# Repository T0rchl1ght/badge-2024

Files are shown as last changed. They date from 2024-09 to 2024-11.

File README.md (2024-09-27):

# OpenTaxus 

| [Readme](/) | [The Attribution Game](/attribution) | [Trick or Treat Game](/trickortreat) | [Badge Hardware](/hardware) |
| --- | --- | --- | --- |

Opentaxus is a permissively licensed set of hardware, software, and tooling to help as a starting point for customized conference badges.

## Motivation
Electronic conference badges are a well appreciated feature of an event, but very quickly become large, complicated projects. Typically there's custom hardware, custom embedded software, and sometimes much more. Every one of thos parts has the potential for schedule delays or causing the whole project to fail. Meanwhile, there's almost always a very hard deadline.

OpenTaxus is intended to get you started with a working system, allowing you to customize only as much as you want to or have time to. You are encouranged to use any or all of the parts of OpenTaxus for your own project

## Badge Games

There are currently two games for OpenTaxus. Each is in it's own subdirectory. Right now you'll just pick one (or make a new one) for your conference badge:

### [The Attribution Game](/attribution)

Similar to the board game Clue or some versions of Carmen Sandiego,
you need to figure out who the threat actor, attack tool, and victim
are for each round of the game. You do this by trading cards (or
'clues') as well as your self-entered alibi name with others
at the conference.

The Attribution Game was designed for [LABScon 2023](https://www.labscon.io/) and then revised and improved for [BSidesSF 2024](https://bsidessf.org/)

### [Trick or Treat Game](/trickortreat) 

In this game, you Trick-or-Treat, trading virtual candy with other conference attendees. Once you have collected enough, you can cash out your virtual candy for real candy or prizes.

The Trick or Treat Game was designed for [BSidesPDX 2024](https://bsidespdx.org/)

## Repo Contents

This repository contains the hardware and software for the badge and multiple games. We hope it is useful for those who wish to hack the badges and game, anyone who wants to use the badge to learn some circuitpython, as well as others who might like to reuse some or all of it for other projects.

The badge hardware was designed and produced by @securityfitz, with variants being used for BSidesSF 2024 and Labscon.
The badge software is a fork of the Labscon badge software, further mangled by @rlc4, @lanrat, and @securelyfitz, and then further forked and mangled by *

## Event Badge Designer Instructions

OpenTaxus is intended to be be a drop-in electronic badge that works from the start. While you can use the badge as it's presented here if you plan to use it for an event or organization, you may want to customize the appearance of the badge, and possibly some of the text and programming. 

### Suggested customizations:
	
#### Physical Appearance:
* Add custom artwork such as your logo to the badges KiCad files (found in the [hardware](/hardware) folder). 
* Add in the name of the artist and contributors to the silkscreen.
* Include the repo for your code or events in the silkscreen on the back of the badge.

#### Electronic text:
* The Attribution Game has a number of custom strings that can be adjusted within the [genfiles.py](./attribution/configs/genfiles.py) file. In particular, you may want to change line 121 to say the name of your event or organization instead of "A mysterious group".
* The same file also includes other bits of flavor text that could be customized to match your event's theme or location.
* Changing the menu text of the badge to show your event name instead of "OpenTaxus" can be done on lines 23 and 139 of [home.py](./attribution/software/home.py)
* Sponsor names can be added within [home.py](./attribution/software/home.py) around line 144.

#### Misc:
* You may also want to change the file that you're reading now ([README.md](README.md)) to welcome your attendee's, ctf players, etc.

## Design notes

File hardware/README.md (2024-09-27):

# Hardware

| [Readme](/) | [The Attribution Game](/attribution) | [Trick or Treat Game](/trickortreat) | [Badge Hardware](/hardware) |
| --- | --- | --- | --- |

`/hardware/` contains the kicad board design files and full details about
design and manufacturing. The hardware on the badge includes:

-  Raspberry Pi 2040, derived from the seeed xiao 2040
-  16MB spi flash for code and files
-  128x64 OLED display with SH1106 or SSD1309 controller over I2C
-  IR LED and Phototransistor used directly on UART.
-  5-way d-pad for input
-  2 neopixel LEDs
-  AA battery plus boost voltage converter
-  USB-C connector plus vreg for usb power
-  power switch to switch between USB and Battery power
-  test points for reset, boot, and swd

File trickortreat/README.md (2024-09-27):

# Trick or Treat Game 

| [Readme](/) | [The Attribution Game](/attribution) | [Trick or Treat Game](/trickortreat) | [Badge Hardware](/hardware) |
| --- | --- | --- | --- |

## Game Overview

In the Trick or Treat game, you get to meet people, trade digital candy, and potentially trade in your digital candy for the real thing.

The OpenTaxus Badge is designed for playing the Attribution Game.
Similar to the board game Clue or some versions of Carmen Sandiego,
you need to figure out who the threat actor, attack tool, and victim
are for each round of the game. You do this by trading cards (or
'clues') as well as your self-entered alibi name with others
at the conference.

## Game Basics

When you first power on your badge, you need to set your handle. This can be any string - your name, email, handle, ICQ number, etc. This will be shared with everyone you interact with. You'll be able to see a list of all the people you interacted with at the conference, too.

You'll be randomly assigned a candy type. You have an unlimited supply of this kind of candy - you can give it freely to everyone you meet and trade with.

When you trade, you'll give the other person your handle and candy type. They'll send the same information back to you. Both of your badges will record this.

On your badge, you can see both your candy inventory, and the list of friends you made along the way.

Once you have collected enough of one type of candy, you can trade it in for the real thing!

## Navigation

There is a 5-way d-pad in the middle of the badge. In general:

- < and > switch between info screens
- ^ and v highlight something
- x (press) to select something

The screens you can navigte between with < and > are:
1. Home Screen where you'll start out:
   - ^ to trade candy
   - x to hear from our sponsors
   - v to turn off your badge
1. Inventory Screen where you can see what candy you have:
   - ^ and v to browse
   - x to see details, and to redeem for the real thing
1. Contacts Screen where you see all your friends:
   - ^ and v to browse
   - x to see what candy they gave you
1. Settings Screen where you can change badge stuff:
   - ^ and v to browse
   - x to change the setting. Some will pop up new screens

## Example Gameplay

1. Set up your badge
   - Start your badge by sliding the power switch to the right. 
   - If you haven't already, enter a handle. Use ^v<> to highlight letters and x to select. 
   - Delete and Done buttons are at the bottom.
   - press x or V to page through a short intro and take you to the home screen.
   - keep pressing x to see details about event sponsors.
1. Trade Candy!
   - Find a person to trade with. 
   - Make smalltalk with them until you have the confidence to ask them for candy.
   - Line your badges up.
   - From the home screen, both of you press '^', one after the other
   - Candy should be traded both ways.
   - If it fails or there's an error, try again
   - Note: Duplicate candies from the same person don't count!
1. See what you've got or configure your badge:
   - Press < or > to navigate to the candy, friend, or setting screen
   - Press ^ or v to scroll through the list of candies/friends/settings
   - Press x to see details
1. Cash out! 
   - Go to the badge prize table
   - Press < or > to navigate to the candy screen
   - Press ^ or v to scroll through the list of candies
   - Press x to see details
   - Line up your badge with the candy validator
   - When told, press ^ to verify your candy earnings
   - Note: There may be a limit to the number of prizes per person
1. HACK!
   - Plug your badge in with a USB cable
   - Your computer should see a read-only USB drive full of python code, and a serial port to connect to the python console
   - Learn about [circuitpython](https://learn.adafruit.com/welcome-to-circuitpython/overview)
   - Read some code to see how it works
   - If you'd like to modify the code on your badge, unplug it and slide the power switch left to the off/usb mode, then plug it back in. The usb drive will now be read/write.

## Repo Contents

* the /trickortreat/ part of the repo is forked from the /attribution/ used for BSidesSF 2024 and developed for BSidesPDX 2024.
* /trickortreat/controller/ contains all the code run on a desktop. This includes generating game files and flashing the badges.
* /trickortreat/badge/ contains the contents of the badge USB storage device, minus the badge-specific parts generated from the controller.

## Event Badge Designer Instructions

To use this game as-is:
1. change necessary strings in controller/strings.py
1. run controller/genfiles.py to generate all the keys and badge-specific files
1. run controller/flash.py to wait for a badge to be attached, then flash it

### Suggested customizations:
	
#### Physical Appearance:
* Add custom artwork such as your logo to the badges KiCad files (found in the [hardware](/hardware) folder). 
* Add in the name of the artist and contributors to the silkscreen.
* Include the repo for your code or events in the silkscreen on the back of the badge.

#### Electronic text:
* With only string changes you can change this from halloween-themed trick-or-treating to any theme and 
* as soon as this is complete, all the easily changed strings will be in /controller/strings.py Right now they're scattered in the code:
  * There are a number of custom strings that can be adjusted within the [genfiles.py](./configs/genfiles.py) file. In particular, you may want to change line 121 to say the name of your event or organization instead of "A mysterious group".
  * The same file also includes other bits of flavor text that could be customized to match your event's theme or location.
  * Changing the menu text of the badge to show your event name instead of "OpenTaxus" can be done on lines 23 and 139 of [home.py](./software/home.py)
  * Sponsor names can be added within [home.py](./software/home.py) around line 144.

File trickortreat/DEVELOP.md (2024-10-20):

# Develop with the OpenTaxus Badge

| [Readme](/) | [The Attribution Game](/attribution) | [Trick or Treat Game](/trickortreat) | [Badge Hardware](/hardware) |
| --- | --- | --- | --- |

## Developing for the badge

Version: CircuitPython 9.1.4; Seeeduino XIAO RP2040

Make sure you use version compatible libraries

### Installing CircuitPython

When the RP2040 boots, it checks for valid data in the spi flash. If it doesn't,
it boots into USB boot-loader mode and shows up as a drive labeled RPI-RP2.
[Download and copy the .UF2 file](https://circuitpython.org/board/seeeduino_xiao_rp2040/)
to the drive and it will reboot into CircuitPython.
If you need to reinstall for any reason, short the 'BOOT' test pads while resetting
the RP2040 and it will go back to the boot-loader mode.

### Installing The Attribution Game

Once CircuitPython is installed, when the badge is plugged in it will show
both a serial port and a drive labeled CIRCUITPY. Copy the entire contents
of `/badge/` in this repository to that drive. the badge will reboot and run the code.

### Provisioning the game data

The `/controller/` directory contains some text files with data specific to
the game. These will be copied along with the rest of the code:

- genfiles generates a pair of keys, and creates 50 variations of game*.csv files
- game*.csv has all the possible clues for each game, and is provisioned with one signed clue per game
- seed.txt needs to be filled with a seed for the random choice of solutions
- priv.json and pub.json are generated by genfiles and contain the game keys which can be used to authenticate the signed
  clues you receive. This is generated by the controller, the public key is copied to all badges

Details about the hardware can be found in [HARDWARE](/Hardware)

## Software

- `./badge/` contains the code on the badge
- `./controller/flash/` contains files and tools for automatically flashing badges
- `./controller/config/` contains tools to generate all of the encrypted badge configurations

### Architecture

Most functions are wrapped inside classes with the priority to make the top level
code more clean and readable versus sticking to a clean object model.

All functions should be non-blocking and quick to make sure the UI doesn't get
frozen and button presses don't get missed. This means stuff like checking for
enough UART valid data before reading it, and scheduling timed actions based on
timestamps instead of sleep() calls

#### Dependencies

- core circuitpython libraries: time,board,busio,pulseio,digitalio,displayio,
  terminalio
- additional adafruit libraries in `/software/lib/`: debouncer,
  ticks, displayio_ssh1106, imageload, display_text

#### Support modules

-  Fake_IRDA.py wraps the UART interface, handles enabling/disabling the
   IRDA enable pin, and stuffing/unstuffing the bytes that are transmitted
   to work with the IRDA phy in the nonstandard way we use it
-  Five_Way_Dpad.py wraps the dpad with the Adafruit Debouncer including
   all setup and a few helper functions for checking all buttons at once. The
   non-blocking update() function needs to be run periodically to capture all
   button presses.
-  sh1106_ui.py/ssd1306.py wraps the I2C display interface, handles the overall display
   view, and creates a separate group for each of the navigation pages. The
   non-blocking show() function should be called periodically to make sure the
   correct view is displayed and to manage the transition animations
-  disp.py wraps the functionality of the pages. The class handles initialization,
   managing the display view, underlying data and operations. Most of this is
   handled in a non-blocking update() function that returns the next state

## Screen

* https://www.arduino.cc/reference/en/libraries/oled-ssd1306-sh1106/
* https://docs.circuitpython.org/projects/displayio_sh1106/en/latest/api.html

Driven by: https://docs.circuitpython.org/en/latest/shared-bindings/displayio/

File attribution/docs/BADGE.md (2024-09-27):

# Using the Badge

| [Readme](/) | [The Attribution Game](/attribution) | [Trick or Treat Game](/trickortreat) | [Badge Hardware](/hardware) |
| --- | --- | --- | --- |

## Setup

When you first power on your badge it will give you a brief intro to
the badge and the game, then it will ask you for your contact info.
This could be a handle, email address, or any other string that will
be shared with everyone you interact with. Use the up and down but
tons to choose letters, left and right to move through the string,
and press the button to set your name. (it can be changed later)

## Navigating

- Left and Right switches between:
  - Home page
  - Alibis page, which shows all the people you've traded contact info and clues with
  - Clues page, which shows all the cards you've collected so far
  - Settings, which allow you to change badge features
- Up takes you to trade mode, described below
- Down puts the badge to sleep, which also happens automatically after a few
   seconds
- Pressing the center button usually gives you more details about whatever you're highlighting.

### Trading

Your badge has an infrared transceiver. Press the 'up' button to enter trade mode.
The badge will:

- transmit your clue as well as your contact information
- listen to receive someone elses card and contact info
- verify the cryptographic signature on the clue
- tell you the result of the trade.
  After the trade, you should be able to see the information in your Contacts an
  Cards pages.

### Winning

The real prize isn't attribution but the contacts and friends we made along the way.
If you happen to have collected enough info to attribute the attack, your badge will
tell you. Find a game organizer to validate your win.

### Multiple rounds

The first round of the game will be pretty easy with only a few trades needed to
attribute. Once a game is complete, the game controller will transmit a packet to
advance the game to the next round, which will propagate to everyone when they
trade clues. Each round will have a different set of cards/clues and a different
attack to attribute.

## After the conference

This badge can work as a simple circuitpython learning platform. The best source
of information about circuitpython is available on Adafruit, including a [Welcome
to CircuitPython guide](https://learn.adafruit.com/welcome-to-circuitpython/overview)

The best place to start tinkering is probably with some neat light animations on
the RGB LED on the badge. Adafruit
[has an example](https://github.com/adafruit/Adafruit_Learning_System_Guides/blob/main/Welcome_to_CircuitPython/code.py)
on how to use this RGB LEDs.

For working interactively with a python CLI, plug your badge in with a USB cable,
and connect to the serial port that shows up.

For writing your own circuitpython programs, you need to modify the code.py
file you can find on the drive that shows up when you plug in the USB cable.
Every time you save the file, the board will reset and start running your code.

If you've somehow messed up your badge, you can follow the process below to
flash a fresh copy of circuitpython and/or the game code.

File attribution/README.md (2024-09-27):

# The Attribution Game 

| [Readme](/) | [The Attribution Game](/attribution) | [Trick or Treat Game](/trickortreat) | [Badge Hardware](/hardware) |
| --- | --- | --- | --- |

## Badge Game

Similar to the board game Clue or some versions of Carmen Sandiego,
you need to figure out who the threat actor, attack tool, and victim
are for each round of the game. You do this by trading cards (or
'clues') as well as your self-entered alibi name with others
at the conference.

## Attribution Game basics

In order to play in the Attribution Game, you will need to enter a name or handle when you first turn on your badge. This will stay through power cycles. It can be cleared in your settings which will force you to enter a new one.

To trade cards with someone, scroll left or right until you get to the "OpenTaxus" screen.
Once there, press the toggle up, and place your badge edge at the top of the screen against
the same badge edge of the person you are trading with. You should see once your card has
been transmitted and you have received a card from them.

You can check your collected cards by scrolling right from the "OpenTaxus" screen.

When you collect enough cards, the one remaining is the solution that completes the phrase. There are 6 games to play through - try them all!

Please see [Using the Badge](/attribution/GAME.md) for more details about interacting with the badge and [Playing the Game](/attribution/GAME.md) for more details about gameplay.

## Repo Contents

This repository contains the hardware and software for
the badge and game. We hope it is useful for those who wish to hack
the badges and game, anyone who wants to use the badge to learn some
circuitpython, as well as others who might like to reuse some or all
of it for other projects.

The badge hardware was designed and produced by @securityfitz, with variants being used for BSidesSF 2024 and Labscon.
The badge software is a fork of the Labscon badge software, further mangled by @rlc4, @lanrat, and @securelyfitz.

## Event Badge Designer Instructions

OpenTaxus is intended to be be a drop-in electronic badge that works from the start. While you can use the badge as it's presented here if you plan to use it for an event or organization, you may want to customize the appearance of the badge, and possibly some of the text and programming. 

Please see [Developer Instrucitons](/attribution/DEVELOP.md) for more details

### Suggested customizations:
	
#### Physical Appearance:
* Add custom artwork such as your logo to the badges KiCad files (found in the [hardware](/hardware) folder). 
*  Add in the name of the artist and contributors to the silkscreen.
* Include the repo for your code or events in the silkscreen on the back of the badge.

#### Electronic text:
* There are a number of custom strings that can be adjusted within the [genfiles.py](./configs/genfiles.py) file. In particular, you may want to change line 121 to say the name of your event or organization instead of "A mysterious group".
* The same file also includes other bits of flavor text that could be customized to match your event's theme or location.
* Changing the menu text of the badge to show your event name instead of "OpenTaxus" can be done on lines 23 and 139 of [home.py](./software/home.py)
* Sponsor names can be added within [home.py](./software/home.py) around line 144.

#### Misc:
* You may also want to change the file that you're reading now ([README.md](README.md)) to welcome your attendee's, ctf players, etc.

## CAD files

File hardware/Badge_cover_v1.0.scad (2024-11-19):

// Please feel free to remix or use this badge cover in any way that keeps with the limits of OpenTexus

// Depending on filament used, the dimensions might need to be adjusted due to shrinking or expanding

// Define constants for reusable values
cylinderOffset = 2;
cylinderYSpacing = 42;
cornerRadius = 5;

// Outer rectangle parameters
length = 86.00;
width = 66.70;
height = 12.00;

// Hole parameters
holeParams = [
    // Bottom Hole
    [4.82, 42.94, height], // Display Hole
    [27.50, 29.00, height],  // Body Hole
    [67.45 + 1.25, 63.70, 10.08], // Battery Hole
    [17.80, 58.00, 3.00],    // Top Hole
    [10.34, 49.00, 10.08],   // D5 Joystick Hole
    [17.00, 17.00, 2.00]     
];

// Function to create a rectangular hole
module rectangular_hole(x, y, z, len, wid, height) {
    translate([x, y, z])
        cube([len, wid, height]);
}

// Function to create a cylindrical hole
module cylindrical_hole(x, y, z, r, height) {
    translate([x, y, z])
        cylinder(r=r, h=height, $fn=100); // $fn sets the resolution of the cylinder
}

// Create the rounded rectangle using hull() for 3D rounded corners
module rounded_rectangle(len, wid, h, rad) {
    hull() {
        translate([rad, rad, 0])
            cylinder(h=h, r=rad);
        translate([len-rad, rad, 0])
            cylinder(h=h, r=rad);
        translate([rad, wid-rad, 0])
            cylinder(h=h, r=rad);
        translate([len-rad, wid-rad, 0])
            cylinder(h=h, r=rad);
    }
}

// Module for the left torus
module left_torus(r1, r2) {
    rotate_extrude(angle = 360)
        translate([r1, 0, 0])  // Keep original center for rotation
        circle(r = r2);
}

// Module for the right torus
module right_torus(r1, r2) {
    rotate_extrude(angle = 360)
        translate([r1, 0, 0])
        circle(r = r2);
}

difference() {
    // Create outer rounded rectangle
    rounded_rectangle(length, width, height, cornerRadius);

    // Create all holes using loop
    // BottomHole
    rectangular_hole(0, (width - holeParams[0][1]) / 2, 0, holeParams[0][0], holeParams[0][1], holeParams[0][2]); 
    // DisplayHole
    rectangular_hole(0, (width - holeParams[1][1]) / 2, 0, holeParams[1][0], holeParams[1][1], holeParams[1][2]); // BodyHole
    rectangular_hole((length - holeParams[2][0]) / 2, (width - holeParams[2][1]) / 2, height - holeParams[2][2], holeParams[2][0], holeParams[2][1], holeParams[2][2]); // BatteryHole
    rectangular_hole(length - holeParams[3][0] - 8.7, (width - holeParams[3][1]) / 2, 0, holeParams[3][0], holeParams[3][1], holeParams[3][2]); // TopHole
    rectangular_hole(length - holeParams[4][0], (width - holeParams[4][1]) / 2, height - holeParams[4][2], holeParams[4][0], holeParams[4][1], holeParams[4][2]); // D5JoystickHole
    rectangular_hole(length - 34.6 - holeParams[5][0], (width - holeParams[5][1]) / 2, 0, holeParams[5][0], holeParams[5][1], holeParams[5][2]);
    
    // Right screw hole
    cylindrical_hole(80, 4.5, 1.5, 1.55, 10.50);
    
    // Left screw hole
    cylindrical_hole(80, 62, 1.5, 1.55, 10.50);
}

// Right torus (Lanyard connector)
translate([length + 2, width - holeParams[4][1] / 5.2, height - holeParams[4][2] - 1.17]) {  // Move torus
    right_torus(r1 = 8 / 2, r2 = 1.56 / 2); 
}

// Left torus (Lanyard connector)
translate([length + 2, (width - holeParams[4][1]) / 2, height - holeParams[4][2] - 1.17]) {  // Move torus
    left_torus(r1 = 8 / 2, r2 = 1.56 / 2);
}

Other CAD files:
hardware/dock.scad

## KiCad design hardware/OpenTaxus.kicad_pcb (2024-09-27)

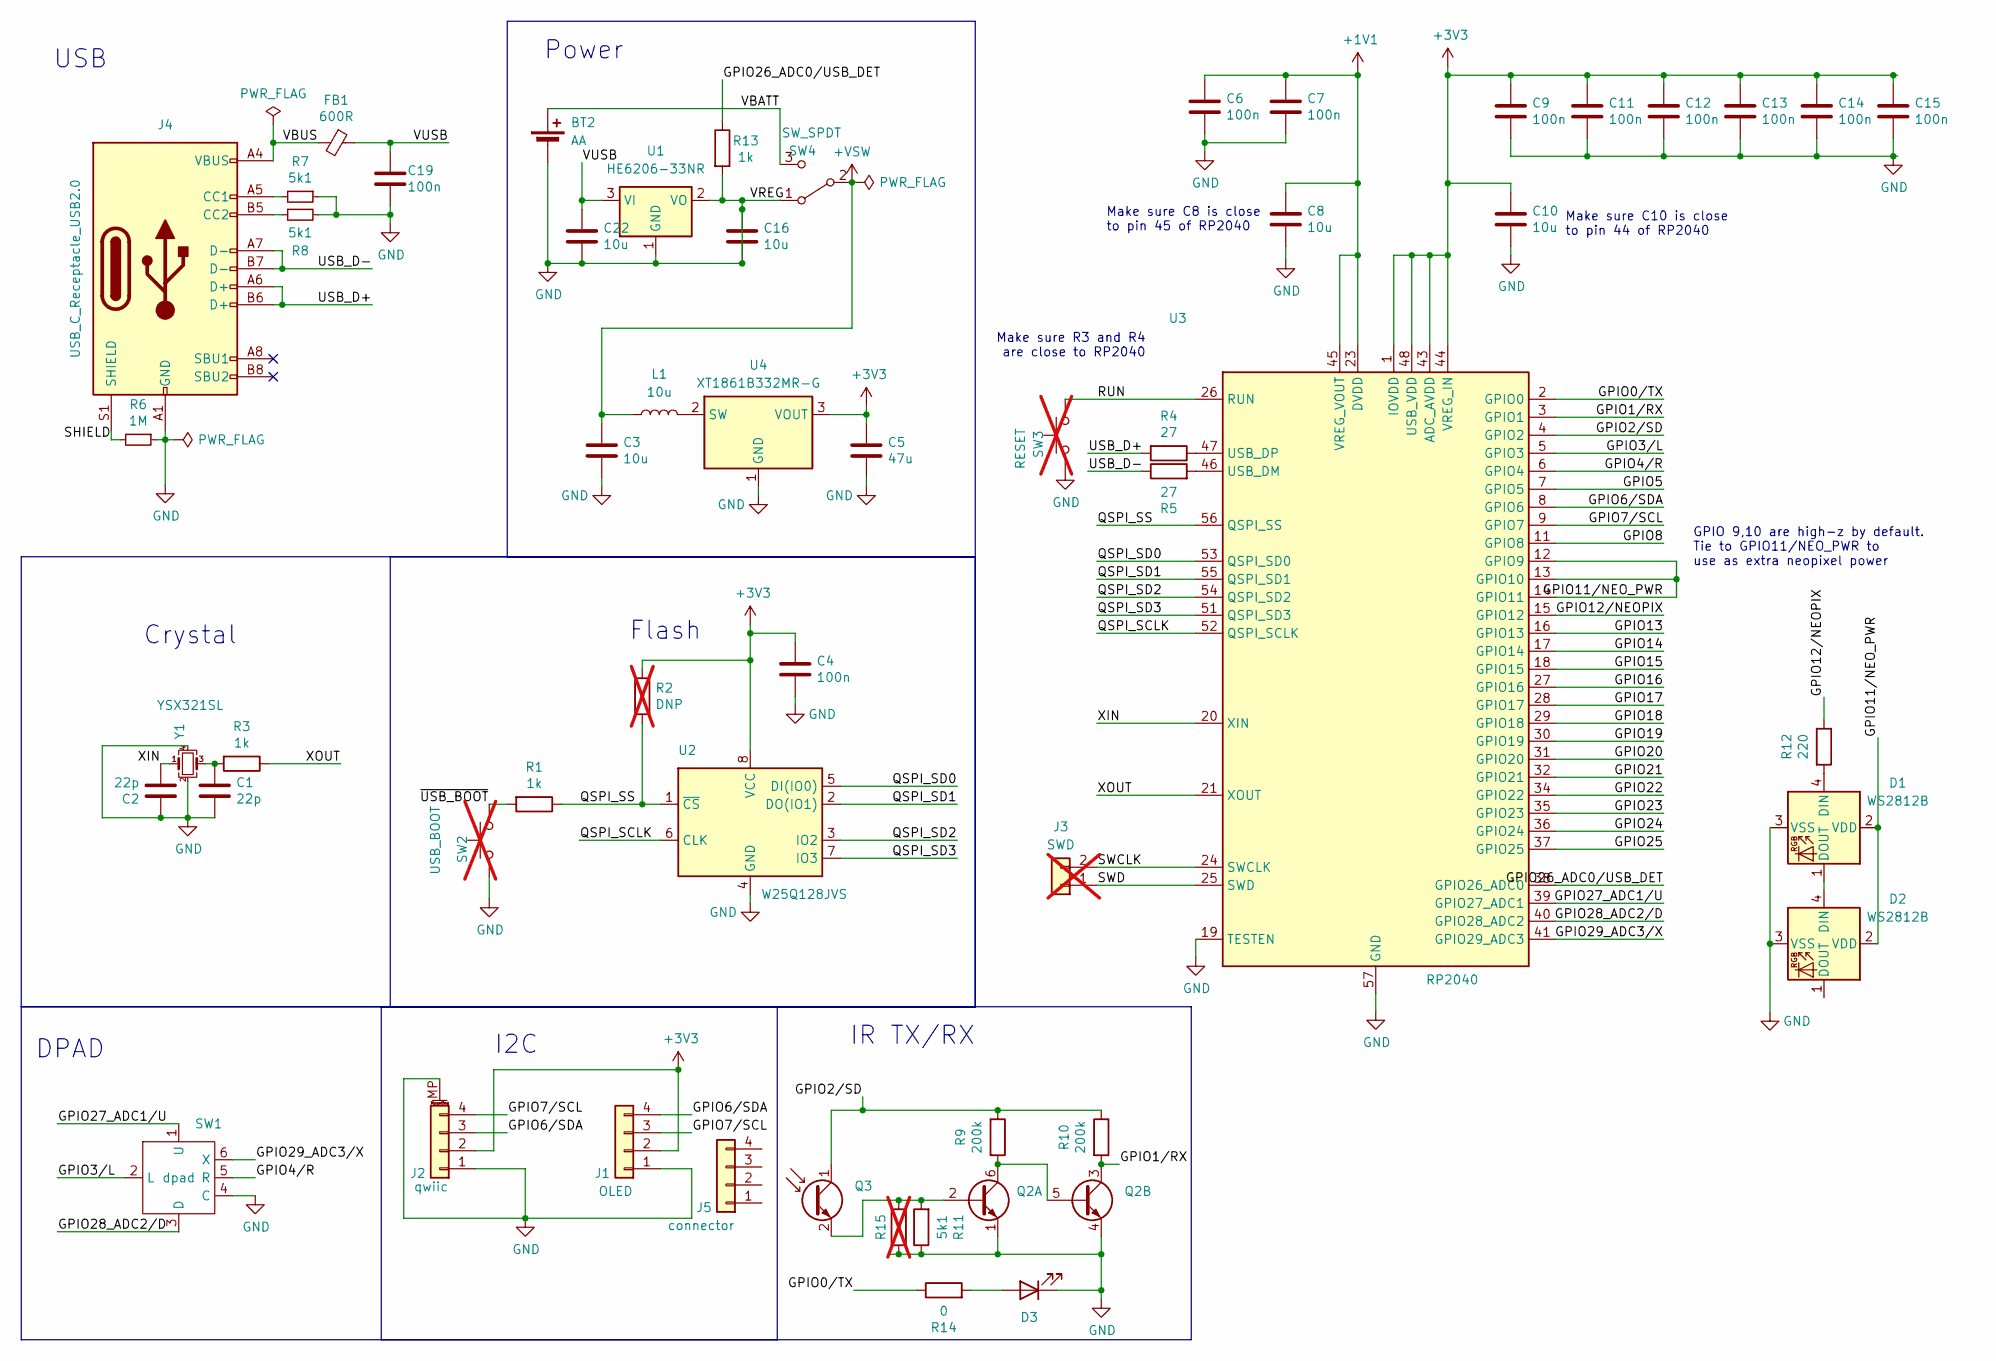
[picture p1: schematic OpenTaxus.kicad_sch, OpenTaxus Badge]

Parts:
BT2: AA; BatteryHolder_Keystone_2460_1xAA; LCSC C5290181
C1, C2: 22p; C_0402_1005Metric; LCSC C106203
C3, C8, C10, C16, C22: 10u; C_0402_1005Metric; LCSC C15525
C4, C6, C7, C9, C11, C12, C13, C14, C15, C19: 100n; C_0402_1005Metric; LCSC C100072
C5: 47u; C_0805_2012Metric; LCSC C16780
D1, D2: WS2812B; LED_WS2812B_PLCC4_1.0x1.0mm; LCSC C5349953
D3: IR12-21C/TR8; IR12-21C-TR8; LCSC C53672
FB1: 600R; L_0402_1005Metric; LCSC C76886
J1: OLED; PinHeader_1x04_P2.54mm_Vertical; LCSC C5248080
J2: qwiic; JST_SH_SM04B-SRSS-TB_1x04-1MP_P1.00mm_Horizontal; LCSC C7433425
J3: SWD; SolderJumper-2_P1.3mm_Open_RoundedPad1.0x1.5mm; LCSC DNP; not fitted
J4: USB_C_Receptacle_USB2.0; USB_C_Receptacle_HRO_TYPE-C-31-M-12; LCSC C2927038
J5: connector; PinHeader_1x04_P2.54mm_Vertical; LCSC C2902691
L1: 10u; L_1008_2520Metric; LCSC C602018
Q2: BC847BS; SOT-363_SC-70-6; LCSC C5380687
Q3: PT12-21B/TR8; PT12-21B-TR8; LCSC C264383
R1, R3, R13: 1k; R_0402_1005Metric; LCSC C11702
R2, R15: DNP; R_0402_1005Metric; LCSC DNP; not fitted
R4, R5: 27; R_0402_1005Metric; LCSC C25100
R6: 1M; R_0402_1005Metric; LCSC C26083
R7, R8, R11: 5k1; R_0402_1005Metric; LCSC C25941
R9, R10: 200k; R_0402_1005Metric; LCSC C25764
R12: 220; R_0402_1005Metric; LCSC C25091
R14: 0; R_0402_1005Metric; LCSC C17168
SW1: dpad; 10x10x10x9-6P-WX; LCSC C2858290
SW2: USB_BOOT; SolderJumper-2_P1.3mm_Open_RoundedPad1.0x1.5mm; LCSC DNP; not fitted
SW3: RESET; SolderJumper-2_P1.3mm_Open_RoundedPad1.0x1.5mm; LCSC DNP; not fitted
SW4: SW_SPDT; SW_SPDT_PCM12; LCSC C319020
U1: HE6206-33NR; SOT-23-3; LCSC C5199441
U2: W25Q128JVS; SOIC-8_5.23x5.23mm_P1.27mm; LCSC C97521
U3: RP2040; QFN-56-1EP_7x7mm_P0.4mm_EP3.2x3.2mm; LCSC C2040
U4: XT1861B332MR-G; SOT-23; LCSC C236396
Y1: YSX321SL; Crystal_SMD_3225-4Pin_3.2x2.5mm; LCSC C9002

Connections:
+1V1: C6.1, C7.1, C8.1, U3.23 (DVDD), U3.45 (VREG_VOUT), U3.50 (DVDD)
+3V3: C4.1, C5.1, C9.1, C10.1, C11.1, C12.1, C13.1, C14.1, C15.1, J1.2, J2.2, R2.1, U2.8 (VCC), U3.1 (IOVDD), U3.10 (IOVDD), U3.22 (IOVDD), U3.33 (IOVDD), U3.42 (IOVDD), U3.43 (ADC_AVDD), U3.44 (VREG_IN), U3.48 (USB_VDD), U3.49 (IOVDD), U4.3 (VOUT)
+VSW: C3.1, L1.1, SW4.2 (B)
/GPIO0/TX: R14.1, U3.2 (GPIO0)
/GPIO1/RX: Q2.3 (C2), R10.2, U3.3 (GPIO1)
/GPIO2/SD: Q3.1 (C), R9.1, R10.1, U3.4 (GPIO2)
/GPIO3/L: SW1.2 (L), U3.5 (GPIO3)
/GPIO4/R: SW1.5 (R), U3.6 (GPIO4)
/GPIO5: U3.7 (GPIO5)
/GPIO6/SDA: J1.4, J2.3, U3.8 (GPIO6)
/GPIO7/SCL: J1.3, J2.4, U3.9 (GPIO7)
/GPIO8: U3.11 (GPIO8)
/GPIO11/NEO_PWR: D1.2 (VDD), D2.2 (VDD), U3.12 (GPIO9), U3.13 (GPIO10), U3.14 (GPIO11)
/GPIO12/NEOPIX: R12.1, U3.15 (GPIO12)
/GPIO13: U3.16 (GPIO13)
/GPIO14: U3.17 (GPIO14)
/GPIO15: U3.18 (GPIO15)
/GPIO16: U3.27 (GPIO16)
/GPIO17: U3.28 (GPIO17)
/GPIO18: U3.29 (GPIO18)
/GPIO19: U3.30 (GPIO19)
/GPIO20: U3.31 (GPIO20)
/GPIO21: U3.32 (GPIO21)
/GPIO22: U3.34 (GPIO22)
/GPIO23: U3.35 (GPIO23)
/GPIO24: U3.36 (GPIO24)
/GPIO25: U3.37 (GPIO25)
/GPIO26_ADC0/USB_DET: R13.1, U3.38 (GPIO26_ADC0)
/GPIO27_ADC1/U: SW1.1 (U), U3.39 (GPIO27_ADC1)
/GPIO28_ADC2/D: SW1.3 (D), U3.40 (GPIO28_ADC2)
/GPIO29_ADC3/X: SW1.6 (X), U3.41 (GPIO29_ADC3)
/QSPI_SCLK: U2.6 (CLK), U3.52 (QSPI_SCLK)
/QSPI_SD0: U2.5 (DI(IO0)), U3.53 (QSPI_SD0)
/QSPI_SD1: U2.2 (DO(IO1)), U3.55 (QSPI_SD1)
/QSPI_SD2: U2.3 (IO2), U3.54 (QSPI_SD2)
/QSPI_SD3: U2.7 (IO3), U3.51 (QSPI_SD3)
/QSPI_SS: R1.1, R2.2, U2.1 (~CS), U3.56 (QSPI_SS)
/RUN: SW3.1, U3.26 (RUN)
/SHIELD: J4.S1 (SHIELD), R6.2
/SWCLK: J3.2, U3.24 (SWCLK)
/SWD: J3.1, U3.25 (SWD)
/USB_D+: J4.A6 (D+), J4.B6 (D+), R4.2
/USB_D-: J4.A7 (D-), J4.B7 (D-), R5.1
/VBATT: BT2.1 (+), SW4.3 (C)
/VBUS: FB1.2, J4.A4 (VBUS), J4.A9 (VBUS), J4.B4 (VBUS), J4.B9 (VBUS)
/VREG: C16.1, R13.2, SW4.1 (A), U1.2 (VO)
/VUSB: C19.1, C22.1, FB1.1, U1.3 (VI)
/XIN: C2.2, U3.20 (XIN), Y1.1
/XOUT: R3.1, U3.21 (XOUT)
/~USB_BOOT: R1.2, SW2.1
GND: BT2.2 (-), C1.2, C2.1, C3.2, C4.2, C5.2, C6.2, C7.2, C8.2, C9.2, C10.2, C11.2, C12.2, C13.2, C14.2, C15.2, C16.2, C19.2, C22.2, D1.3 (VSS), D2.3 (VSS), D3.2 (K), J1.1, J2.1, J2.MP (MountPin), J4.A1 (GND), J4.A12 (GND), J4.B1 (GND), J4.B12 (GND), Q2.1 (E1), Q2.4 (E2), R6.1, R7.1, R8.2, R11.1, R15.1, SW1.4 (C), SW2.2, SW3.2, U1.1 (GND), U2.4 (GND), U3.19 (TESTEN), U3.57 (GND), U4.1 (GND), Y1.2, Y1.4
unnamed: C1.1, R3.2, Y1.3
unnamed: D1.4 (DIN), R12.2
unnamed: D1.1 (DOUT), D2.4 (DIN)
unnamed: D3.1 (A), R14.2
unnamed: J4.A5 (CC1), R7.2
unnamed: J4.B5 (CC2), R8.1
unnamed: Q2.2 (B1), Q3.2 (E), R11.2, R15.2
unnamed: Q2.5 (B2), Q2.6 (C1), R9.2
unnamed: R5.2, U3.46 (USB_DM)
unnamed: R4.1, U3.47 (USB_DP)
unnamed: L1.2, U4.2 (SW)

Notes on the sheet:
DPAD
Make sure C10 is close to pin 44 of RP2040
Make sure C8 is close to pin 45 of RP2040
IR TX/RX
USB
I2C
Make sure R3 and R4 are close to RP2040
Flash
Crystal
Power
GPIO 9,10 are high-z by default. Tie to GPIO11/NEO_PWR to use as extra neopixel power

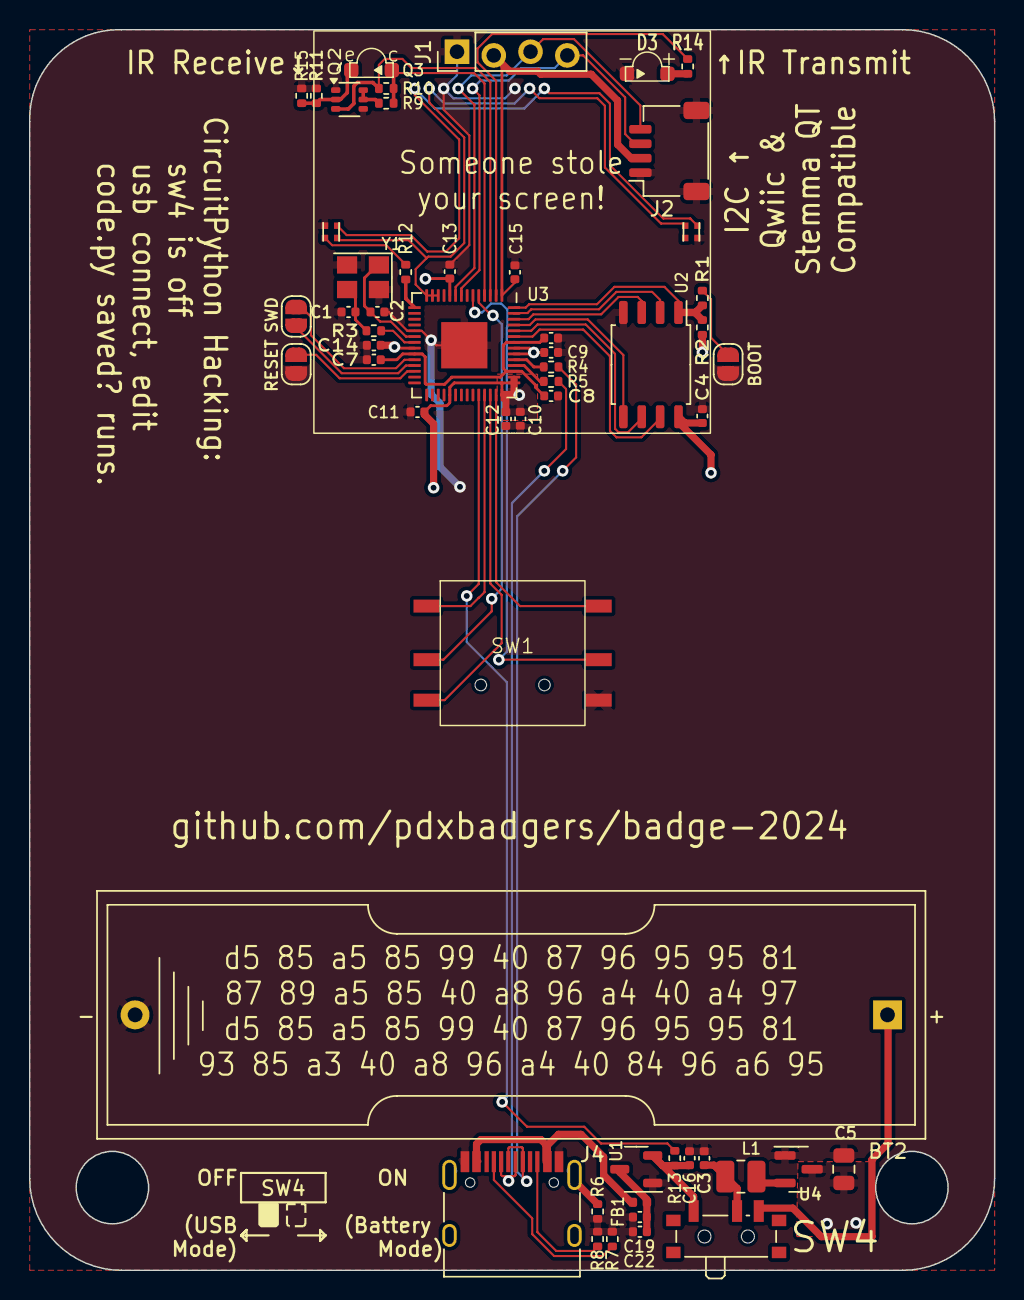
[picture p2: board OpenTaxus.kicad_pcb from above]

Board: 2 copper layers, 66.7 x 85.7 mm, 54 parts (0 on the bottom side), 47 nets.

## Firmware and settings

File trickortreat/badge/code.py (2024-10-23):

import time
from ssd1306_ui import ssd1306ui
from five_way_pad import FiveWayPad
from disp import disp

from leds import led_control
from home import home
from candy import candies
from friends import friends
from settings import settings
from trade import trade
from sleep import sleep
from game import game_data
import gc

BLACK=0x000000
WHITE=0xFFFFFF



#display, dpad, and leds wrap access to physical I/O
display=ssd1306ui()
dpad=FiveWayPad()
leds=led_control()

#disp is the smart scroll-text display
l_disp = disp(display.homegroup, dpad)

#next, load game data including username
game=game_data()

#create the other view pages, most of which need to access
#a single display group, dpad state, and game data
homepage=home(l_disp, dpad, game)
candies_page=candies(l_disp,dpad,game)
settings_page=settings(display.settingsgroup,dpad,game,leds,l_disp)
friends_page=friends(l_disp,dpad,game)
trade_page=trade(dpad,game,l_disp)
sleep_page=sleep(display,dpad,leds)
gc.collect()

#start out on the home page
page="home"
last_page="home"

# TODO unused
SLEEP_TIMEOUT=90

# ToDo: If not configured, run through configuration steps
while True:
    #update leds and display
    leds.animate()
    gc.collect()
    if page!=0: display.show(page)

    #scan inputs
    dpad.update()

    #sleep if it's been a while - except trade page
    if dpad.duration() > settings_page.timeout and page != "trade":
        page=sleep_page.update()

    #if a button is pressed, handle it
    if not dpad.pressed():
        time.sleep(0.001)
    elif page == "home":
        last_page=page
        page=homepage.update()
    elif page == "settings":
        last_page=page
        page=settings_page.update()
    elif page == "friends":
        last_page=page
        page=friends_page.update()
    elif page == "candies":
        last_page=page
        page=candies_page.update()
    elif page == "trade":
        page=trade_page.update()
    elif page == "sleep":
        page=sleep_page.update()
    else: page=last_page

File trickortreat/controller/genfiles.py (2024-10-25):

#!/usr/bin/python3
import random
import os
import sys
import binascii
import adafruit_rsa
import json
from math import ceil, log10, floor
import pyudev
import time
import subprocess
from threading import Thread
import time
import hashlib


#this should do all the event-specific stuff
# todo: regenerate signatures if a new key was generated
# todo: parameterize the file load/unload/generate

candies=["Sour Patch Kids","Haribo Gummies","Smarties","Reese's Cups","Twix","Snickers"]
badge_count=900  #overestimate this! Actually, maybe it shouldn't be settable? maybe dynamic? hmm.
exchange_ratio=5 #how many unique signatures can be redeemed for real candy
hash_method="SHA-256"
checkdir="./checkdir/" #path to store check files

#if keys are present, load them. if not, generate them
try:
    with open("priv.json", "r") as f:
        private_obj = json.loads(f.read())
        private_key=adafruit_rsa.PrivateKey(*private_obj["private_key_arguments"])
        public_key=adafruit_rsa.PublicKey(private_key.n, private_key.e)
    print("\n1. Prior keys loaded from priv.json.")
except Exception as e:
    if input("\nNo keys found, generate them? 'yes' to continue, anything else to quit\n") != "yes":
        exit(1)
    #remove all other config files, or set flag?
    print("1. Generating new keys...")
    (public_key, private_key) = adafruit_rsa.newkeys(512)
    public_obj = {"public_key_arguments": [public_key.n, public_key.e]}
    private_obj = { "private_key_arguments": [private_key.n, private_key.e,
                    private_key.d, private_key.p, private_key.q]}

    #probably should remove this since it's uncessessary and redundant to priv.json
    with open("pub.json", "w") as f:
        f.write(json.dumps(public_obj))

    with open("../badge/pub.json", "w") as f:
        f.write(json.dumps(public_obj))

    with open("priv.json", "w") as f:
        f.write(json.dumps(private_obj))
    print(private_key)

# check for seed, if not present, set the random seed so that game files are deterministic (not used in trick or treat)
try:
    with open("seed.txt", 'r') as file:
        seed = file.read()
        random.seed(seed)
    print("\n2. Prior seed loaded from seed.txt.")
except Exception as e:
    if input("\nNo random seed found, generate one? 'yes' to continue, anything else to quit\n") != "yes":
        exit(1)
    print("2. Choosing new random seed... ")
    seed = random.randrange(sys.maxsize)
    rng = random.Random(seed)
    f=open("seed.txt", "w")
    f.write(str(seed))
    f.close
    print("seed:", seed)


signatures={}

# if signatures are present, load them. If not, generate them.
try:
    with open("candies.json", 'r') as f:
        signatures = json.loads(f.read())
    print("\n3. Prior candies loaded from candies.json.")
except Exception as e:
    if input("\nNo candy signatures found, generate them? 'yes' to continue, anything else to quit\n") != "yes":
        exit(1)
    print("3. Generating new candy signatures..")
    candyCount=ceil(badge_count/len(candies))
    maxCandy=10**ceil(log10(candyCount))-1
    for i in range(candyCount):
        for candy in candies:
            unique_candy=candy + " #" + str(maxCandy-i)
            signatures[unique_candy]=str(binascii.b2a_base64(adafruit_rsa.sign(unique_candy.encode(), private_key, hash_method)))
    with open("candies.json", "w") as f:
        f.write(json.dumps(signatures))
    #print(signatures)


assignments={}
# if assignments are present, load them. If not, generate them.
try:
    with open("assignments.json", 'r') as f:
        assignments = json.loads(f.read())
    print("\n4. Prior assignments loaded from assignments.json.")
except Exception as e:
    if input("\nNo prior assignments found, start from scratch? 'yes' to continue, anything else to quit\n") != "yes":
        exit(1)
    print("4. New assignments log ready...")

allcandies=list(signatures.keys())

print("\nKeys, candies, and signatures loaded. Entering flashing mode.")
print("if mounting gets messy, run the following line to clear out stale mountpoints in /media/\n")
print("    sudo umount /media/sd*; sudo rm /media/sd*/.created_by_pmount; sudo rmdir /media/sd*")
print("\n\nNow, plug in some badges!!\n")

context = pyudev.Context()
monitor = pyudev.Monitor.from_netlink(context)
monitor.filter_by('block')
circuitpy="adafruit-circuitpython-seeeduino_xiao_rp2040-en_US-9.1.4.uf2"
rpi_nuke="flash_nuke.uf2"
cpy_nuke="code.py"
gamefiles="../badge/*"

# write the correct id.json file for this badge serial number to the indicated destination
def registerserial(sn,dest):
    # if a new serial, assign the next candy
    if sn not in assignments:
        #todo: handle overflow here - more than the max # of badges seen!
        candyid=allcandies[len(assignments)]
        print(sn+" now assigned to give out "+candyid)
        assignments[sn]=candyid
    else:
        print(sn+" was already assigned "+assignments[sn])

    # always write out to destination
    with open(dest,"w") as f:
        f.write(json.dumps({'name': '', 'candy': assignments[sn], 'signature': signatures[assignments[sn]]}))

    # update our database
    with open("assignments.json", 'w') as f:
        f.write(json.dumps(assignments))

# node is a badge that was just plugged in. Mount it and return mount point.
def mountnode(node):
    subprocess.run("pmount "+node,shell=True)
    cmd='mount | grep '+node+' | cut -d " " -f 3'
    mountpoint=str(subprocess.check_output(cmd,shell=True),'UTF-8').strip()
    #print(node," was mounted at ",mountpoint)
    return mountpoint

# unmount the badge at this mount point
def umountpoint(mountpoint):
    cmd="sync -d "+mountpoint+" && pumount "+mountpoint
    subprocess.run(cmd,shell=True)
    #print(mountpoint, " unmounted - unplug it")

# copy this file from the badge at this mount point to a unique file locally:
def copyfromdevice(file, mountpoint):
    src=mountpoint+"/"+file
    if not os.path.exists(src): return False
    dest=checkdir+"-".join([time.strftime("%Y%m%d-%H%M%S-"),device.get('ID_SERIAL_SHORT'),file])
    #print("copying from ", src, "to", dest)
    cmd="cp -Lr "+src+" "+dest
    subprocess.run(cmd,shell=True)
    if not os.path.exists(dest): return False
    return dest

# copy this file to the badge at this mount point 
def copytodevice(file, mountpoint):
    #print("copying ", file, " to ", mountpoint)
    cmd="cp -Lr "+file+" "+mountpoint+"/ && sync -d "+mountpoint
    subprocess.run(cmd,shell=True)
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

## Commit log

2024-08-30 adding bsidespdx logo to badge
    [OpenTaxus.kicad_pcb]
2024-08-30 remove unused i2c header
    [OpenTaxus.kicad_sch]
2024-08-30 fine tune via locaions to be hidden by black soldermask
    [OpenTaxus.kicad_pcb]
2024-09-27 changing readme and file setup preparing for a second game
    [dock.scad]
2024-09-27 minor settings tweak for bom and bsidespdx artwork
    [OpenTaxus.kicad_pcb, OpenTaxus.kicad_sch]
2024-10-08 Adding in existing ToT and badge code
    [alibis.csv, game0.csv, game1.csv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]
2024-10-19 moving code into badge; removing poc code
    [alibis.csv, game0.csv, game1.csv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]
2024-10-20 fixing alibi->friend in friends.py
    [friends.py]
2024-10-20 moving dock to hardware; ignoring generated .json files
    [dock.scad]
2024-10-20 removing badge-specific files and adding to gitignore
    [alibis.csv, game0.csv, game1.csv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]
2024-10-20 one more clue->candy swap
    [candy.py]
2024-10-21 Switch over game data structure to trick or treat, with json
2024-10-22 fixed wrong candy name displayed on console
    [candy.py]
2024-10-22 fixing up friends list with test data
    [friends.py]
2024-10-23 bugfixes to support changes to trade.py
    [game.py]
2024-10-23 fixed string index method not available in circuitpython
2024-10-24 fixing mistaken extra comment
    [home.py]
2024-10-24 fixes contriubted by Smiley0x1
    [genfiles.py]
